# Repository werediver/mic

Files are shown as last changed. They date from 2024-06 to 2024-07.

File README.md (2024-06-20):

# Microphone interface

A phantom-powered balanced interface for an [electret microphone](https://en.wikipedia.org/wiki/Electret_microphone) capsule with a built-in [JFET](https://en.wikipedia.org/wiki/JFET).

This interface has no gain, except for doubling the amplitude while converting the single-ended signal
from the capsule into a balanced output signal.

The PCB is designed to fit into a metal tube ⌀11.5 or wider.

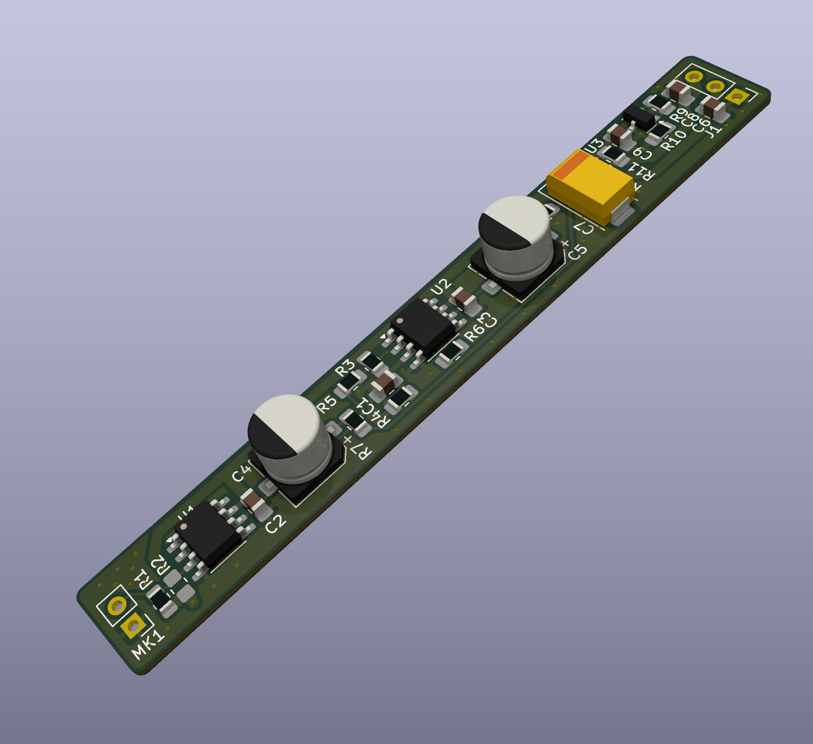
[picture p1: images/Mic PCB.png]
Interface PCB CGI


Please note that two OPA1641 ICs are used in the design just because I already had them when designing the circuit. Using OPA1642 would be more space-efficient and I recommend you using OPA1642, not OPA1641 in your design.

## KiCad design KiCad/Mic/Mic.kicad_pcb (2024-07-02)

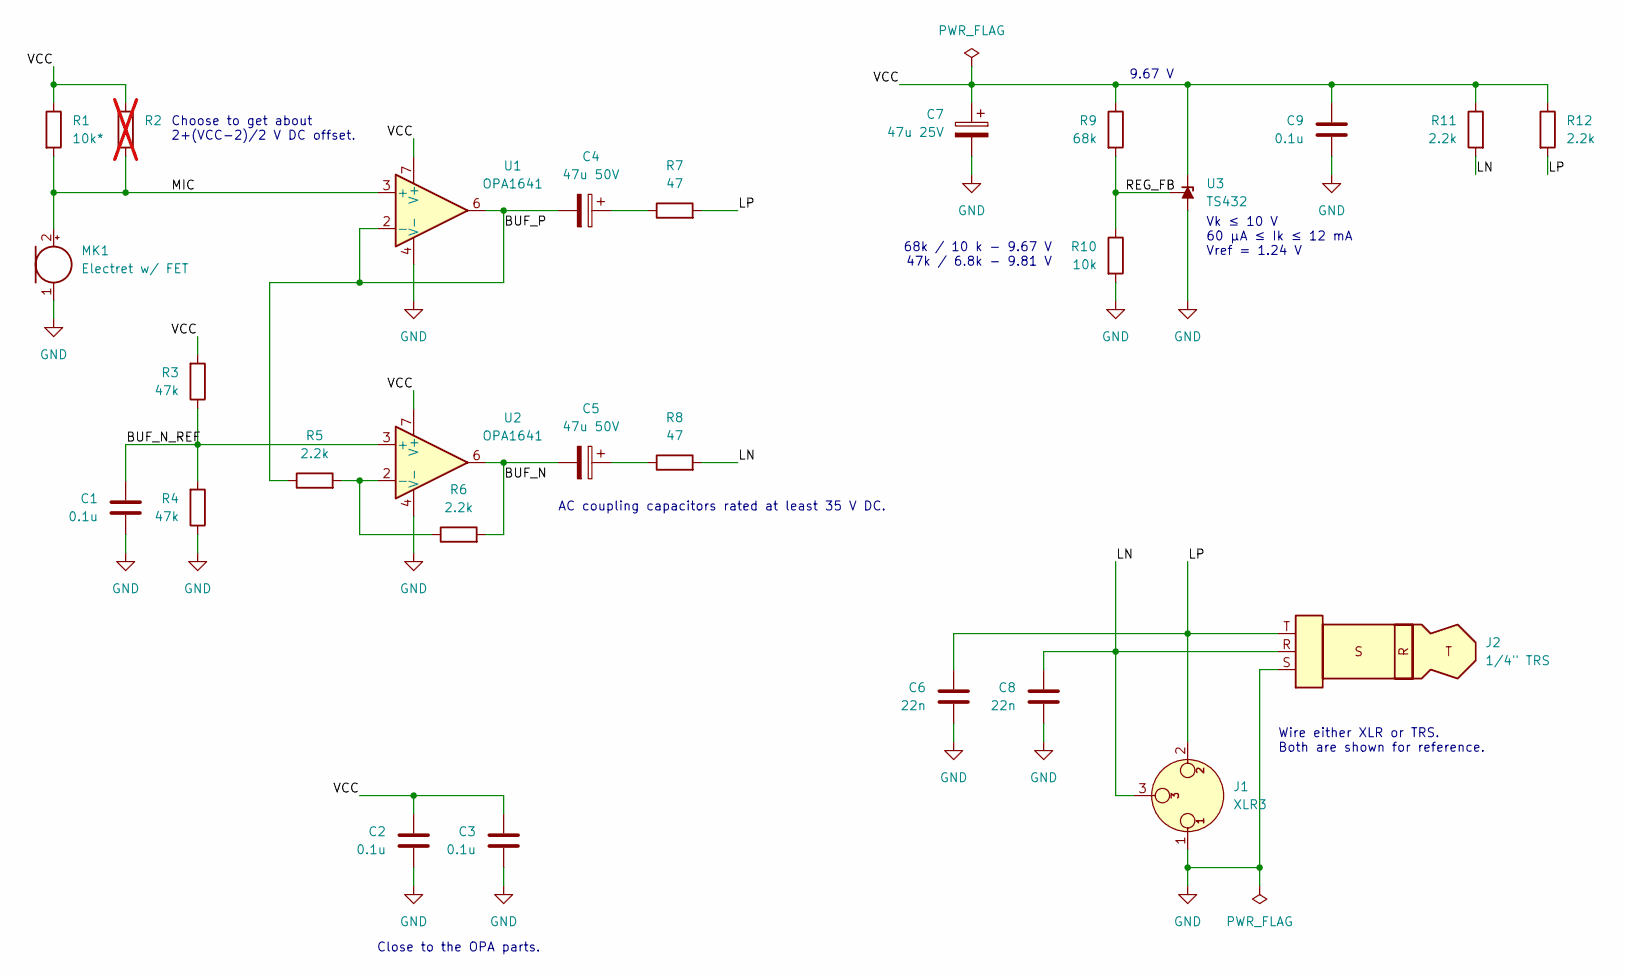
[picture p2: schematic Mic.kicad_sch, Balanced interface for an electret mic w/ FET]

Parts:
C1, C2, C3, C9: 0.1u; C_0805_2012Metric_Pad1.18x1.45mm_HandSolder
C4, C5: 47u 50V; CP_Elec_6.3x5.8
C6, C8: 22n; C_0805_2012Metric_Pad1.18x1.45mm_HandSolder
C7: 47u 25V; CP_EIA-7343-31_Kemet-D_Pad2.25x2.55mm_HandSolder
J1: XLR3; PinHeader_1x03_P2.54mm_Vertical
J2: 1/4" TRS
MK1: Electret w/ FET; PinHeader_1x02_P2.54mm_Vertical
R1: 10k*; R_0805_2012Metric_Pad1.20x1.40mm_HandSolder
R2: R_0805_2012Metric_Pad1.20x1.40mm_HandSolder; not fitted
R3, R4: 47k; R_0805_2012Metric_Pad1.20x1.40mm_HandSolder
R5, R6, R11, R12: 2.2k; R_0805_2012Metric_Pad1.20x1.40mm_HandSolder
R7, R8: 47; R_0805_2012Metric_Pad1.20x1.40mm_HandSolder
R9: 68k; R_0805_2012Metric_Pad1.20x1.40mm_HandSolder
R10: 10k; R_0805_2012Metric_Pad1.20x1.40mm_HandSolder
U1, U2: OPA1641; SOIC-8_3.9x4.9mm_P1.27mm
U3: TS432; SOT-23

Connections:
/BUF_N: C5.2, R6.2, U2.6
/BUF_N_REF: C1.1, R3.1, R4.2, U2.3 (+)
/BUF_P: C4.2, R5.1, U1.2 (-), U1.6
/LN: C8.1, J1.3, J2.R, R8.2, R11.2
/LP: C6.1, J1.2, J2.T, R7.2, R12.2
/MIC: MK1.2 (+), R1.2, R2.2, U1.3 (+)
/REG_FB: R9.2, R10.1, U3.1 (REF)
/VCC: C2.1, C3.1, C7.1, C9.1, R1.1, R2.1, R3.2, R9.1, R11.1, R12.1, U1.7 (V+), U2.7 (V+), U3.2 (K)
GND: C1.2, C2.2, C3.2, C6.2, C7.2, C8.2, C9.2, J1.1, J2.S, MK1.1 (-), R4.1, R10.2, U1.4 (V-), U2.4 (V-), U3.3 (A)
unnamed: C4.1, R7.1
unnamed: C5.1, R8.1
unnamed: R5.2, R6.1, U2.2 (-)

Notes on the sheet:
Wire either XLR or TRS. Both are shown for reference.
68k / 10 k - 9.67 V 47k / 6.8k - 9.81 V
Choose to get about 2+(VCC-2)/2 V DC offset.
AC coupling capacitors rated at least 35 V DC.
Close to the OPA parts.
9.67 V
Vk ≤ 10 V 60 μA ≤ Ik ≤ 12 mA Vref = 1.24 V

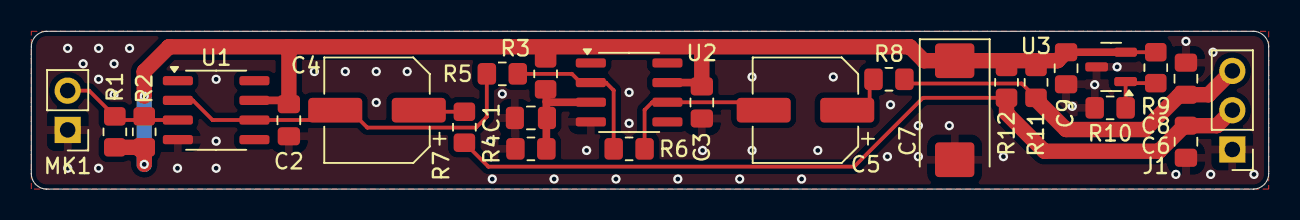
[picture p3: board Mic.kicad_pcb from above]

Board: 2 copper layers, 80.0 x 10.2 mm, 26 parts (0 on the bottom side), 12 nets.

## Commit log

2024-06-20 Add the first revision of the mic interface
    [Mic.kicad_pcb, Mic.kicad_sch]
2024-07-02 Minor updates to the scematic and the PCB
    [Mic.kicad_pcb, Mic.kicad_sch]
